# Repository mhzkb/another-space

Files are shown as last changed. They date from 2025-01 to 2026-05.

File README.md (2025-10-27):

# Another Space

14.25u ortholinear mechanical keyboard with support for up to 4 spacebars, built with PCB, plate and backplate made from FR4.

Untested 15u version is available in [1.5](1.5/).

## Hardware needed
- Pro Micro compatible controller
- 4x Brass stand-offs - 5 mm or longer
- 8x M2 screws - 4 mm
- 4-8 silicone bump-ons eg. 6x2 mm 
- 40-44 SOD-123 diodes
- 40-44 MX switches
- Keycaps

## Firmware
Firmware is available in my [Vial fork](https://github.com/mhzkb/vial-qmk/tree/vial/keyboards/mhzkb) (May need to be size-optimised for non-RP2040 controllers)

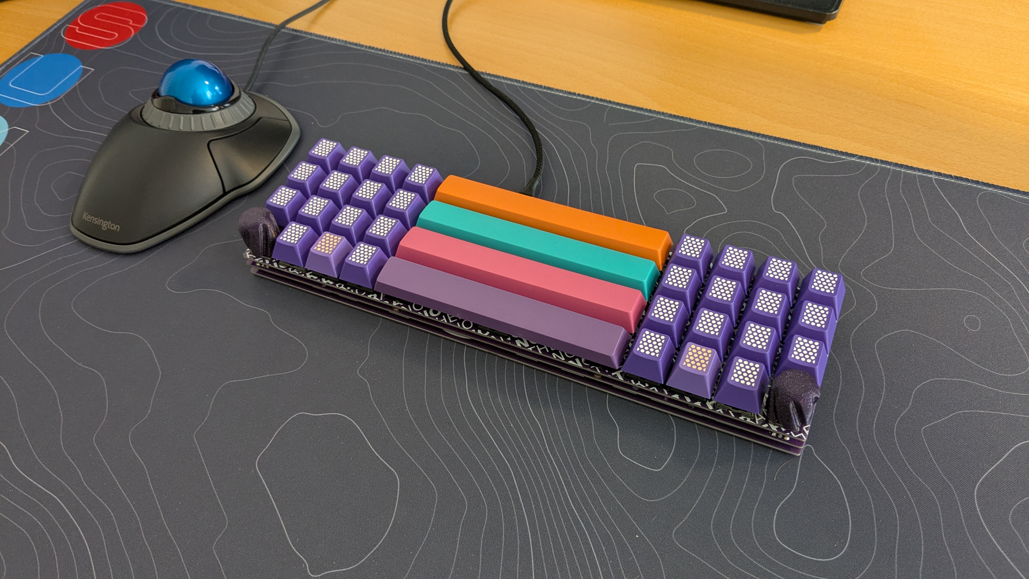
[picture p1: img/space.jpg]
keyboard A very silly yet functional keyboard


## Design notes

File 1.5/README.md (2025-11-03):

# Another Space 1.5

Extended version of Another Space with support for 15u bars and alpha stagger.

__Untested PCB - Proceed at your own risk!__

Note 15u stabs are only supported for the the bottom row. For the remaining rows either use 7u stabs or update the footprints in the Kicad files.

## PCB

### Front
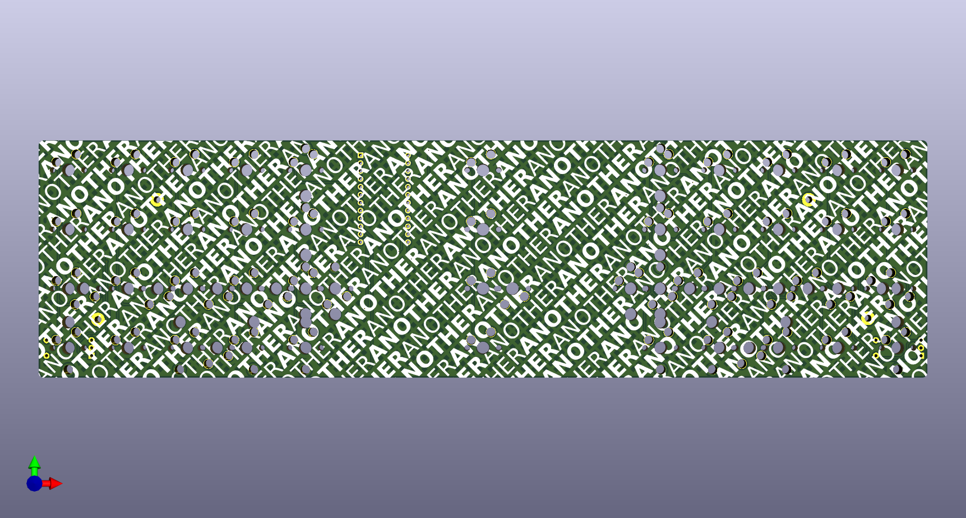
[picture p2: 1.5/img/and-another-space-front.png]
PCB front Front of PCB


### Back
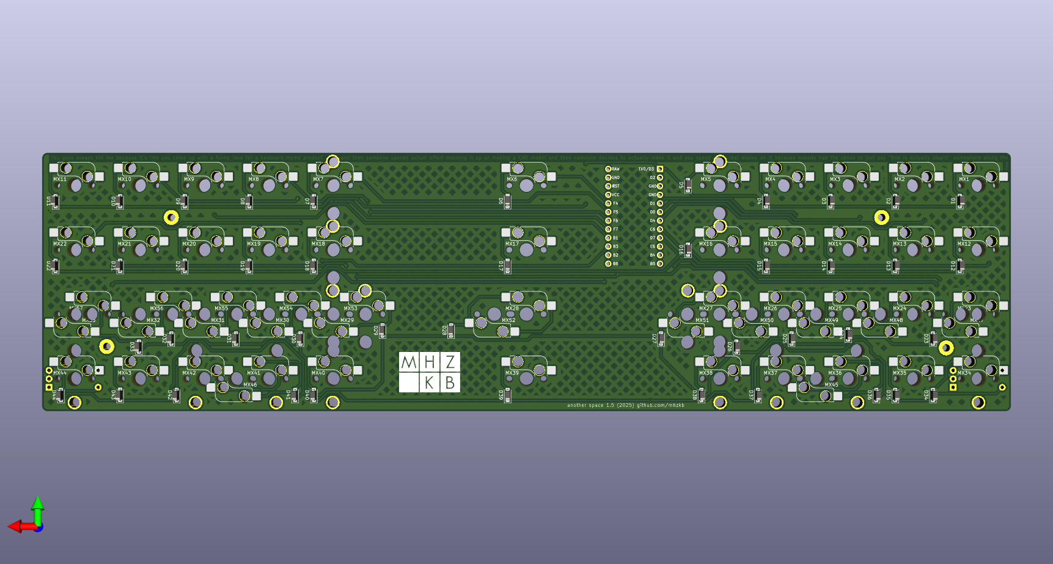
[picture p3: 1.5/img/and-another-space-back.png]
PCB back Back of PCB


## KLC
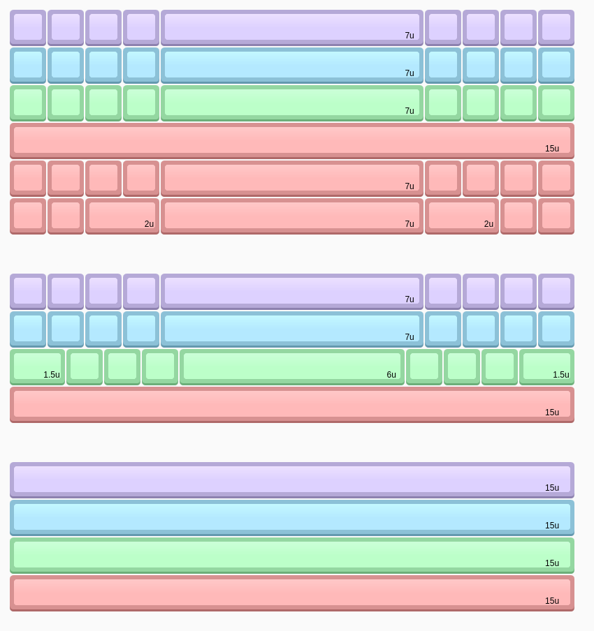
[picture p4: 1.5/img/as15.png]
KLC layout Layout made with Keyboard Layout Creator


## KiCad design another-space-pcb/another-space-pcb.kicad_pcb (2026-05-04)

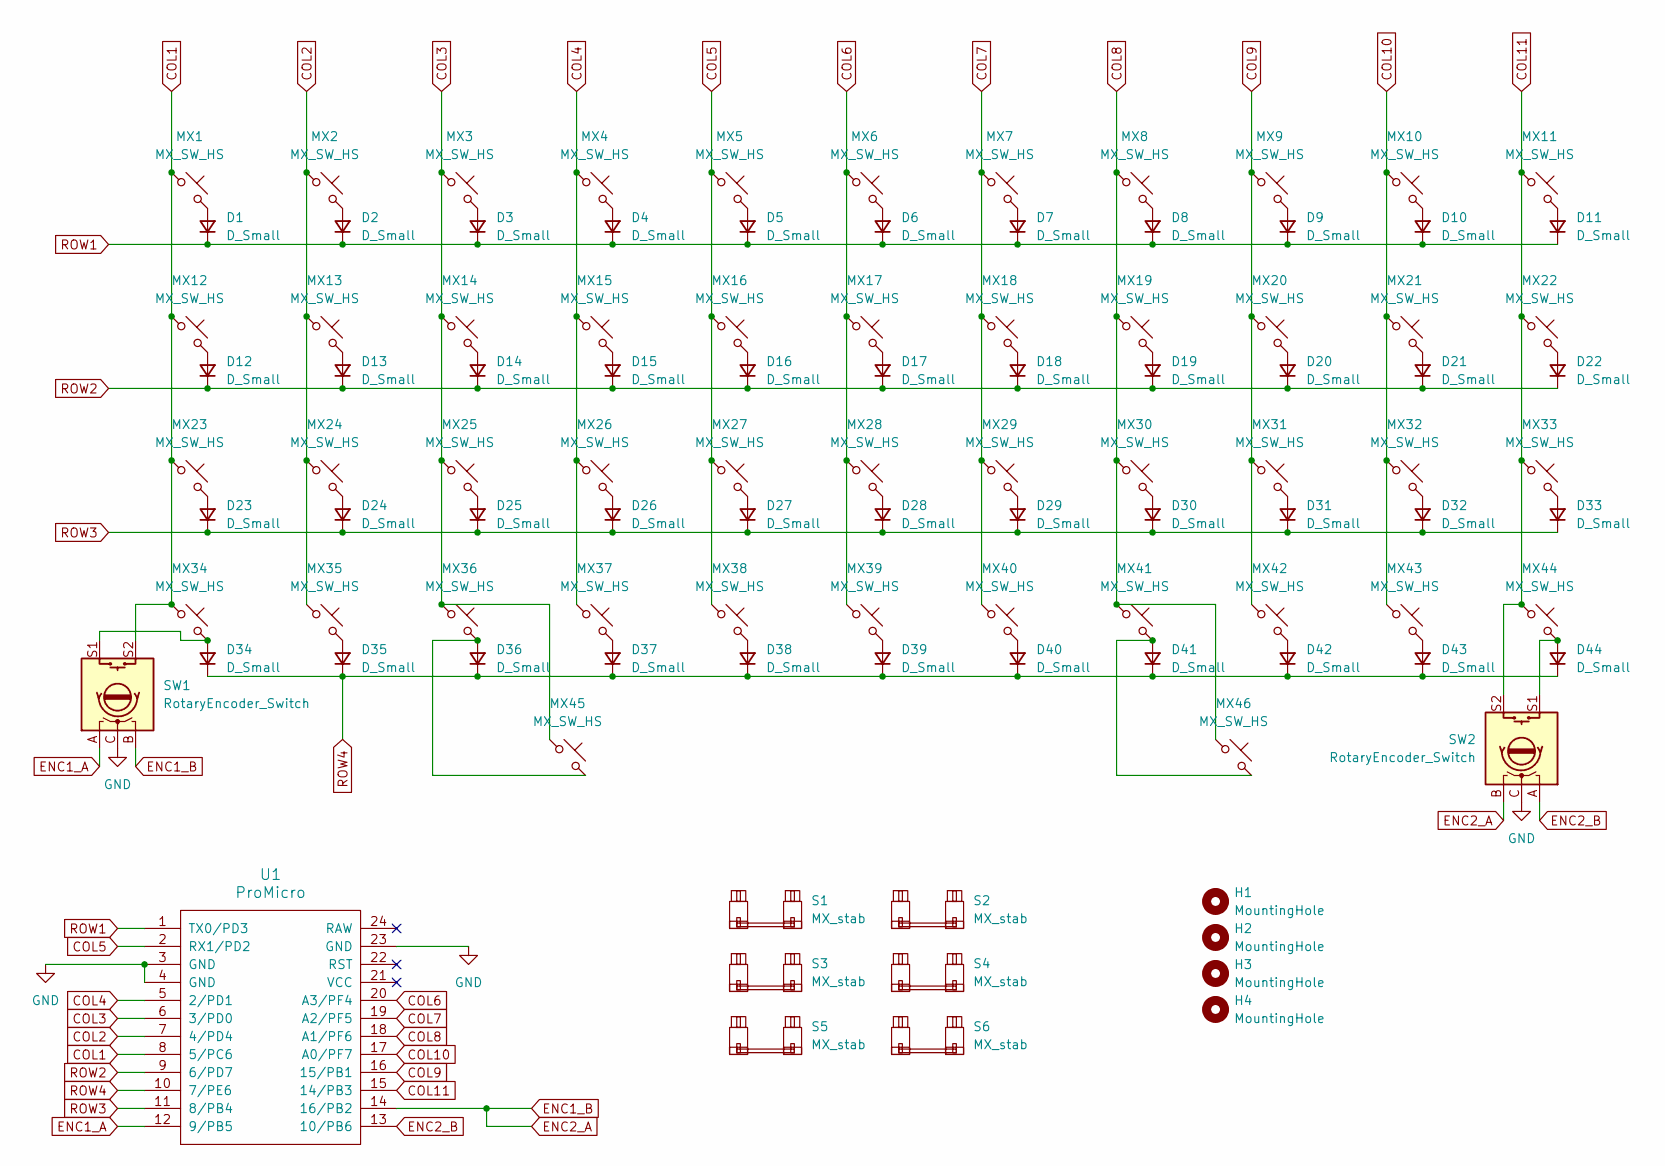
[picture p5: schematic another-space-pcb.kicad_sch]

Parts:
D1, D2, D3, D4, D5, D6, D7, D8, D9, D10, D11, D12, D13, D14, D15, D16, D17, D18, D19, D20, D21, D22, D23, D24, D25, D26, D27, D28, D29, D30, D31, D32, D33, D34, D35, D36, D37, D38, D39, D40, D41, D42, D43, D44: D_Small; D_SOD-123
H1, H2, H3, H4: MountingHole; MountingHole_2.2mm_M2_Pad
MX1, MX2, MX3, MX4, MX5, MX6, MX7, MX8, MX9, MX10, MX11, MX12, MX13, MX14, MX15, MX16, MX17, MX18, MX19, MX20, MX21, MX22, MX23, MX24, MX25, MX26, MX27, MX28, MX29, MX30, MX31, MX32, MX33, MX34, MX35, MX36, MX37, MX38, MX39, MX40, MX41, MX42, MX43, MX44, MX45, MX46: MX_SW_HS; SW_MX_HS_CPG151101S11_1u
S1, S2, S3, S4: MX_stab; STAB_MX_P_6.25u
S5, S6: MX_stab; STAB_MX_P_2u
SW1, SW2: RotaryEncoder_Switch; RotaryEncoder_EC11-no-legs
U1: ProMicro; ArduinoProMicro

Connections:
COL1: MX1.1, MX12.1, MX23.1, MX34.1, SW1.S2, U1.8 (5/PC6)
COL2: MX2.1, MX13.1, MX24.1, MX35.1, U1.7 (4/PD4)
COL3: MX3.1, MX14.1, MX25.1, MX36.1, MX45.1, U1.6 (3/PD0)
COL4: MX4.1, MX15.1, MX26.1, MX37.1, U1.5 (2/PD1)
COL5: MX5.1, MX16.1, MX27.1, MX38.1, U1.2 (RX1/PD2)
COL6: MX6.1, MX17.1, MX28.1, MX39.1, U1.20 (A3/PF4)
COL7: MX7.1, MX18.1, MX29.1, MX40.1, U1.19 (A2/PF5)
COL8: MX8.1, MX19.1, MX30.1, MX41.1, MX46.1, U1.18 (A1/PF6)
COL9: MX9.1, MX20.1, MX31.1, MX42.1, U1.16 (15/PB1)
COL10: MX10.1, MX21.1, MX32.1, MX43.1, U1.17 (A0/PF7)
COL11: MX11.1, MX22.1, MX33.1, MX44.1, SW2.S2, U1.15 (14/PB3)
ENC1_A: SW1.A, U1.12 (9/PB5)
ENC1_B: SW1.B, SW2.B, U1.14 (16/PB2)
ENC2_B: SW2.A, U1.13 (10/PB6)
GND: SW1.C, SW2.C, U1.3 (GND), U1.4 (GND), U1.23 (GND)
unnamed: D1.2 (A), MX1.2
unnamed: D2.2 (A), MX2.2
unnamed: D3.2 (A), MX3.2
unnamed: D4.2 (A), MX4.2
unnamed: D5.2 (A), MX5.2
unnamed: D6.2 (A), MX6.2
unnamed: D7.2 (A), MX7.2
unnamed: D8.2 (A), MX8.2
unnamed: D9.2 (A), MX9.2
unnamed: D10.2 (A), MX10.2
unnamed: D11.2 (A), MX11.2
unnamed: D12.2 (A), MX12.2
unnamed: D13.2 (A), MX13.2
unnamed: D14.2 (A), MX14.2
unnamed: D15.2 (A), MX15.2
unnamed: D16.2 (A), MX16.2
unnamed: D17.2 (A), MX17.2
unnamed: D18.2 (A), MX18.2
unnamed: D19.2 (A), MX19.2
unnamed: D20.2 (A), MX20.2
unnamed: D21.2 (A), MX21.2
unnamed: D22.2 (A), MX22.2
unnamed: D23.2 (A), MX23.2
unnamed: D24.2 (A), MX24.2
unnamed: D25.2 (A), MX25.2
unnamed: D26.2 (A), MX26.2
unnamed: D27.2 (A), MX27.2
unnamed: D28.2 (A), MX28.2
unnamed: D29.2 (A), MX29.2
unnamed: D30.2 (A), MX30.2
unnamed: D31.2 (A), MX31.2
unnamed: D32.2 (A), MX32.2
unnamed: D33.2 (A), MX33.2
unnamed: D34.2 (A), MX34.2, SW1.S1
unnamed: D35.2 (A), MX35.2
unnamed: D36.2 (A), MX36.2, MX45.2
unnamed: D37.2 (A), MX37.2
unnamed: D38.2 (A), MX38.2
unnamed: D39.2 (A), MX39.2
unnamed: D40.2 (A), MX40.2
unnamed: D41.2 (A), MX41.2, MX46.2
unnamed: D42.2 (A), MX42.2
unnamed: D43.2 (A), MX43.2
unnamed: D44.2 (A), MX44.2, SW2.S1
ROW1: D1.1 (K), D2.1 (K), D3.1 (K), D4.1 (K), D5.1 (K), D6.1 (K), D7.1 (K), D8.1 (K), D9.1 (K), D10.1 (K), D11.1 (K), U1.1 (TX0/PD3)
ROW2: D12.1 (K), D13.1 (K), D14.1 (K), D15.1 (K), D16.1 (K), D17.1 (K), D18.1 (K), D19.1 (K), D20.1 (K), D21.1 (K), D22.1 (K), U1.9 (6/PD7)
ROW3: D23.1 (K), D24.1 (K), D25.1 (K), D26.1 (K), D27.1 (K), D28.1 (K), D29.1 (K), D30.1 (K), D31.1 (K), D32.1 (K), D33.1 (K), U1.11 (8/PB4)
ROW4: D34.1 (K), D35.1 (K), D36.1 (K), D37.1 (K), D38.1 (K), D39.1 (K), D40.1 (K), D41.1 (K), D42.1 (K), D43.1 (K), D44.1 (K), U1.10 (7/PE6)

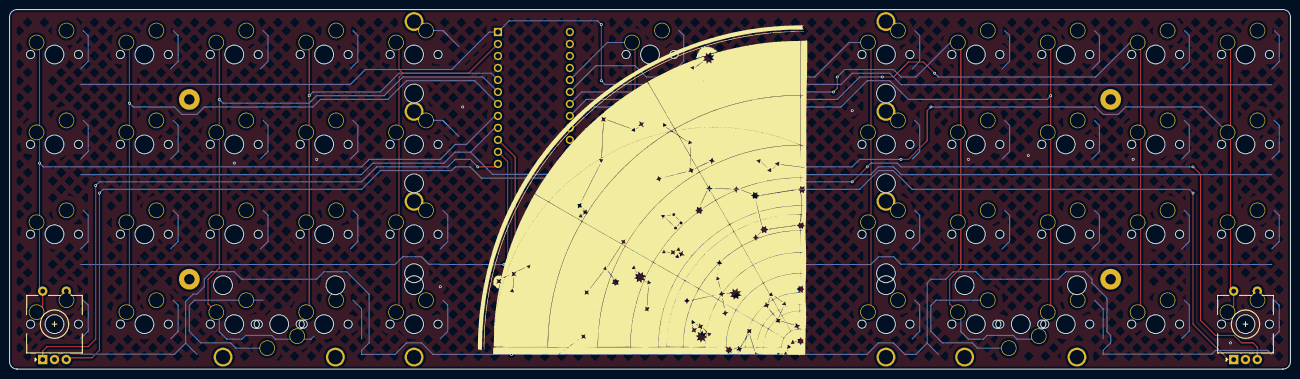
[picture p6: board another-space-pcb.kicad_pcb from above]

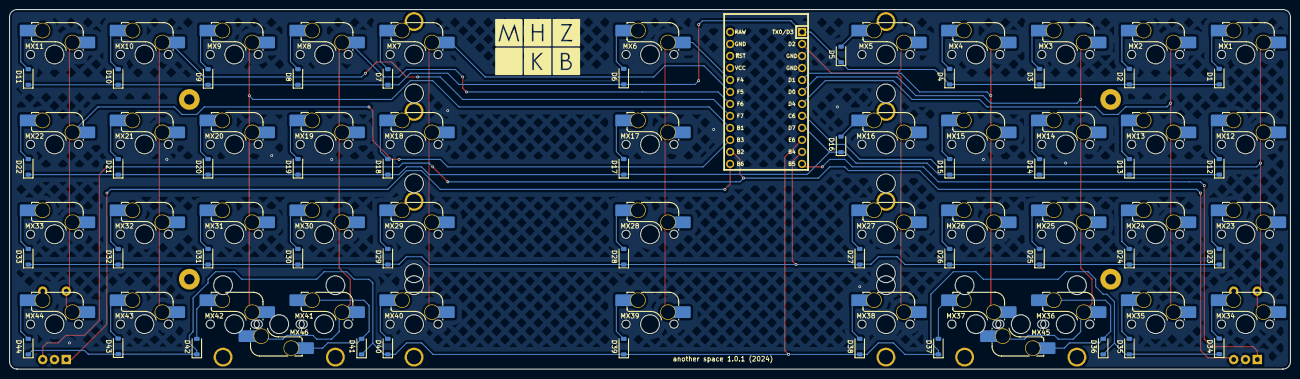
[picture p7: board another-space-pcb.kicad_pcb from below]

Board: 2 copper layers, 271.5 x 76.2 mm, 103 parts (90 on the bottom side), 63 nets.

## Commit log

2025-10-27 Added 15u version
    [and-another-space.kicad_sch]
2026-05-04 Updated pcb silkscreen
    [another-space-pcb.kicad_pcb]
2026-05-04 Updated 1.5 pcb silkscreen
